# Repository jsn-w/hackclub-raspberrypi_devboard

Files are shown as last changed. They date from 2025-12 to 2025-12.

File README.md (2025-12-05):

# hackclub-raspberrypi_devboard
The hackclub-raspberrypi_devboard is a custom development board designed to be simple and easy to use, similar to an Arduino, but build with a RaspberryPi microcontroller.
There are many features, such as compatibility with USB-C, supports breadboard pitch, and works with different software (Arduino, CircuitPython, etc).

# Features, materials
- 29 GPIO pins (4 of them are also ADC)
- Voltage Regulator
- 12 MHz crystal oscillator
- External flash chip

# Schematic!


# PCB
The PCB was made within KiCad and has two layers, where the top and bottom layer both connect to GND. It would be beneficial to have a four layer PCB instead of two since the routings would be done easier by setting adding another power plane for 3.3V or VCC.


<p>There are currently errors for the flash chip since it was imported. The pads are too close to each other but I couldn't find a way to edit them.</p>


# Materials Used
- 1x USB_C_Receptacle_USB2.0_14P
- 1x MCP1700x-330xxTT
- 1x W25Q16JVUXIQ_TR
- 1x Crystal_SMD_3225
- 2x 01x20 pin connector
- 1x 01x03 pin connector
Capacitors
- 11x 100nF
- 2x  1uF
- 2x  10uF
- 2x  33pF
Resistors
- 4x 1.5k
- 1x 1k
- 2x 27

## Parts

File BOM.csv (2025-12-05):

Quantity | Cost | Part | Description | Link
1 | 0.29 | USB_C_Receptacle_USB2.0_14P | USB C Port | https://www.snapeda.com/parts/USB4105GFA/Global%20Connector%20Technology/view-part/
1 | 0.54 | MCP1700x-330xxTT | Low Dropout Regulator (LDO) | https://www.digikey.com/en/products/detail/microchip-technology/MCP1700T-3502E-TT/9643116?gclsrc=aw.ds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
1 | 0.67 | W25Q16JVUXIQ_TR | 16Mbit SPI Flash Memory | https://www.digikey.com/en/products/detail/winbond-electronics/W25Q16JVUXIQ-TR/15182017
1 | 0.38 | Crystal_SMD_3225 | SMD Crystal Oscillator (3225) | https://www.digikey.com/en/products/detail/abracon-llc/ABM8-12.000MHZ-12-B1U-T/9998039?gclsrc=aw.ds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

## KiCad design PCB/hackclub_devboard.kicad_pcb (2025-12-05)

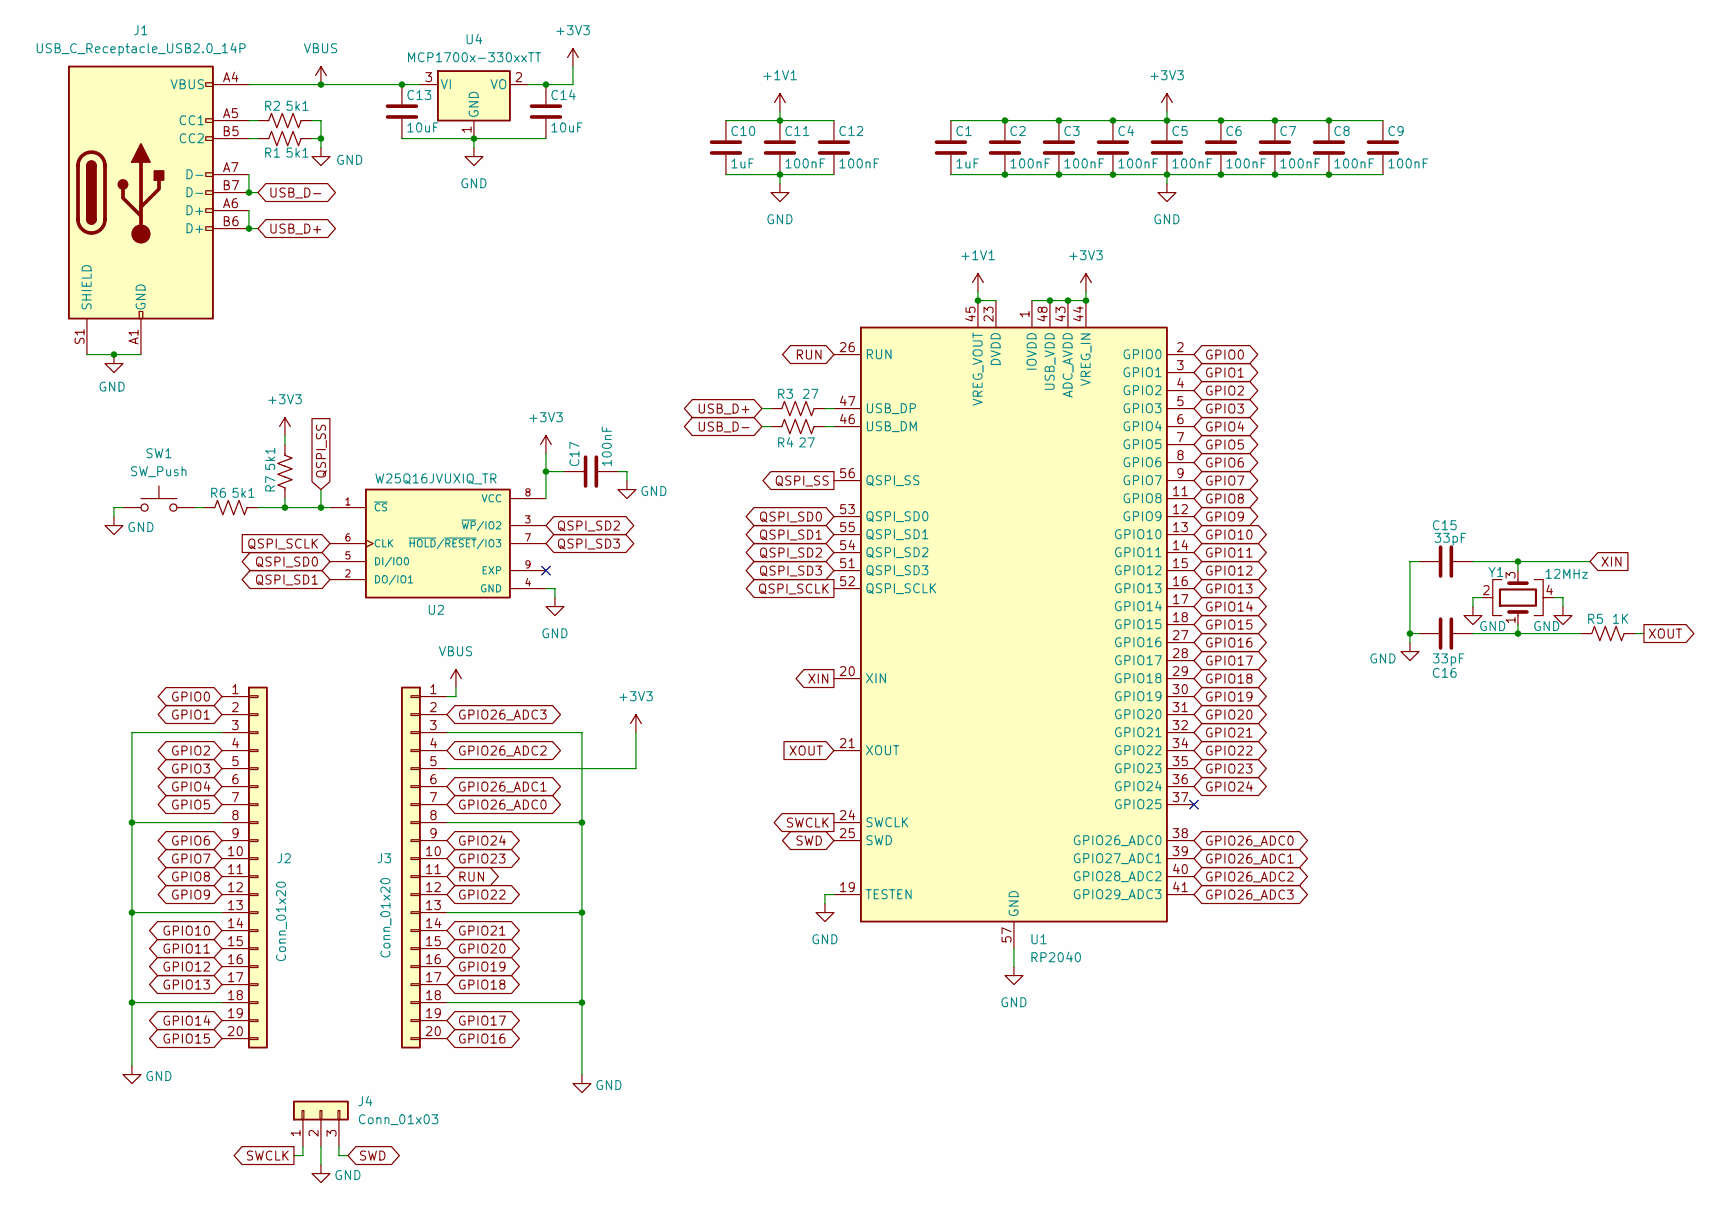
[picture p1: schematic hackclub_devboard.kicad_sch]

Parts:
C1, C10: 1uF; C_0402_1005Metric
C2, C3, C4, C5, C6, C7, C8, C9, C11, C12, C17: 100nF; C_0402_1005Metric
C13, C14: 10uF; C_0603_1608Metric
C15, C16: 33pF; C_0402_1005Metric
J1: USB_C_Receptacle_USB2.0_14P; USB_C_Receptacle_HRO_TYPE-C-31-M-12
J2, J3: Conn_01x20; PinHeader_1x20_P2.54mm_Vertical
J4: Conn_01x03; PinHeader_1x03_P2.54mm_Vertical
R1, R2, R6, R7: 5k1; R_0402_1005Metric
R3, R4: 27; R_0402_1005Metric
R5: 1K; R_0402_1005Metric
SW1: SW_Push; Crystal_SMD_3225-4Pin_3.2x2.5mm
U1: RP2040; QFN-56-1EP_7x7mm_P0.4mm_EP3.2x3.2mm
U2: W25Q16JVUXIQ_TR; IC_W25Q16JVUXIQ_TR; PARTREV H
U4: MCP1700x-330xxTT; SOT-23
Y1: 12MHz; Crystal_SMD_3225-4Pin_3.2x2.5mm

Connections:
+1V1: C10.1, C11.1, C12.1, U1.23 (DVDD), U1.45 (VREG_VOUT), U1.50 (DVDD)
+3V3: C1.1, C2.1, C3.1, C4.1, C5.1, C6.1, C7.1, C8.1, C9.1, C14.1, C17.1, J3.5, R7.2, U1.1 (IOVDD), U1.10 (IOVDD), U1.22 (IOVDD), U1.33 (IOVDD), U1.42 (IOVDD), U1.43 (ADC_AVDD), U1.44 (VREG_IN), U1.48 (USB_VDD), U1.49 (IOVDD), U2.8 (VCC), U4.2 (VO)
GND: C1.2, C2.2, C3.2, C4.2, C5.2, C6.2, C7.2, C8.2, C9.2, C10.2, C11.2, C12.2, C13.2, C14.2, C15.1, C16.1, C17.2, J1.A1 (GND), J1.A12 (GND), J1.B1 (GND), J1.B12 (GND), J1.S1 (SHIELD), J2.3, J2.8, J2.13, J2.18, J3.3, J3.8, J3.13, J3.18, J4.2, R1.2, R2.2, SW1.1, U1.19 (TESTEN), U1.57 (GND), U2.4 (GND), U4.1 (GND), Y1.2, Y1.4
GPIO0: J2.1, U1.2 (GPIO0)
GPIO1: J2.2, U1.3 (GPIO1)
GPIO2: J2.4, U1.4 (GPIO2)
GPIO3: J2.5, U1.5 (GPIO3)
GPIO4: J2.6, U1.6 (GPIO4)
GPIO5: J2.7, U1.7 (GPIO5)
GPIO6: J2.9, U1.8 (GPIO6)
GPIO7: J2.10, U1.9 (GPIO7)
GPIO8: J2.11, U1.11 (GPIO8)
GPIO9: J2.12, U1.12 (GPIO9)
GPIO10: J2.14, U1.13 (GPIO10)
GPIO11: J2.15, U1.14 (GPIO11)
GPIO12: J2.16, U1.15 (GPIO12)
GPIO13: J2.17, U1.16 (GPIO13)
GPIO14: J2.19, U1.17 (GPIO14)
GPIO15: J2.20, U1.18 (GPIO15)
GPIO16: J3.20, U1.27 (GPIO16)
GPIO17: J3.19, U1.28 (GPIO17)
GPIO18: J3.17, U1.29 (GPIO18)
GPIO19: J3.16, U1.30 (GPIO19)
GPIO20: J3.15, U1.31 (GPIO20)
GPIO21: J3.14, U1.32 (GPIO21)
GPIO22: J3.12, U1.34 (GPIO22)
GPIO23: J3.10, U1.35 (GPIO23)
GPIO24: J3.9, U1.36 (GPIO24)
GPIO26_ADC0: J3.7, U1.38 (GPIO26_ADC0)
GPIO26_ADC1: J3.6, U1.39 (GPIO27_ADC1)
GPIO26_ADC2: J3.4, U1.40 (GPIO28_ADC2)
GPIO26_ADC3: J3.2, U1.41 (GPIO29_ADC3)
unnamed: C16.2, R5.1, Y1.1
unnamed: J1.A5 (CC1), R2.1
unnamed: J1.B5 (CC2), R1.1
unnamed: R6.1, SW1.2
unnamed: R4.1, U1.46 (USB_DM)
unnamed: R3.2, U1.47 (USB_DP)
QSPI_SCLK: U1.52 (QSPI_SCLK), U2.6 (CLK)
QSPI_SD0: U1.53 (QSPI_SD0), U2.5 (DI/IO0)
QSPI_SD1: U1.55 (QSPI_SD1), U2.2 (DO/IO1)
QSPI_SD2: U1.54 (QSPI_SD2), U2.3 (~WP/IO2)
QSPI_SD3: U1.51 (QSPI_SD3), U2.7 (~HOLD/~RESET/IO3)
QSPI_SS: R6.2, R7.1, U1.56 (QSPI_SS), U2.1 (~CS)
RUN: J3.11, U1.26 (RUN)
SWCLK: J4.1, U1.24 (SWCLK)
SWD: J4.3, U1.25 (SWD)
USB_D+: J1.A6 (D+), J1.B6 (D+), R3.1
USB_D-: J1.A7 (D-), J1.B7 (D-), R4.2
VBUS: C13.1, J1.A4 (VBUS), J1.A9 (VBUS), J1.B4 (VBUS), J1.B9 (VBUS), J3.1, U4.3 (VI)
XIN: C15.2, U1.20 (XIN), Y1.3
XOUT: R5.2, U1.21 (XOUT)

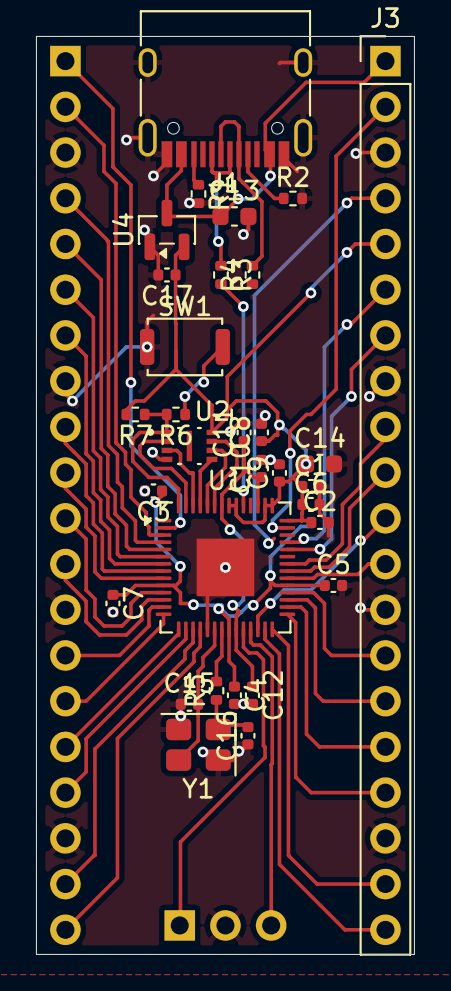
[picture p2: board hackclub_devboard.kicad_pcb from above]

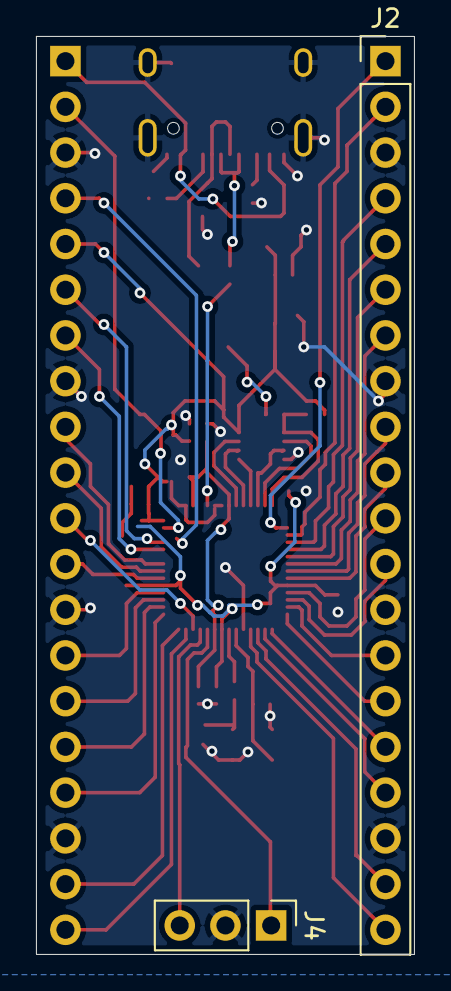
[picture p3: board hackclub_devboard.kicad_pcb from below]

Board: 2 copper layers, 21.0 x 51.0 mm, 33 parts (2 on the bottom side), 52 nets.

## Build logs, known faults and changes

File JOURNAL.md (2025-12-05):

# journal
Estimated time: 10 hours

## Firmware!
<p>This process took 2.5 hours (and counting) and was done on 12/2 but I didn't get the chance to actually journal this on time on the site.</p>
<p>This microcontroller could be used for anything, but I wanted to make a game similar to pacman, or pong. I have an Arduino UNO R4 Minima where I started prototyping the game. It includes having a joystick to control the position of the cursor. Once the devboard is assembled, I will transfer the Arduino program over.</p>


## Wiring the schematic
<p>I wired all the schematic on 12/3-12/4, and this process took approximately 2.5 hours</p>
<p>I routed the PCB, getting help from the <a href="https://pip-assets.raspberrypi.com/categories/814-rp2040/documents/RP-008371-DS-1-rp2040-datasheet.pdf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" target="_blank">RP2040 Datasheet</a>, page 11.</p>



<p>This helped me figure out what and where to connect the pins. I also found placing global labels to be really nice. Here is an image of me actually wiring things on a STM32 board:</p>

<p>Net labels makes it a lot cleaner since there aren't routings going everywhere.</p>
<p>Something really annoying about this portion is finding the right schematic and footprint for a part that you want to use, oftentimes there aren't any CAD files for the footprints.</p>

## Tracing PCB
<p>Tracing the pcb took approximately 5 hours and was completed on 12/4-12/5. It still needs some improvements on wiring so that it is more organized.</p>
<p>First, I placed everything in their relative spots based on the diagram below.</p>

<p>Then, I made sure that some modules were really close to the microcontroller (decoupling capacitors, crystal oscillators)</p>
<p>I realized that on a small board, the decoupling capacitors wouldn't be able to be that close to the microcontroller since there's a lot of wiring going on around those pins.</p>

<p>For a lot of the routing, I had to move a lot of wires down for optimal spacing so I can actually fit some of the capacitors and other components in.</p>
<p>In this portion, I had to rewire the entire section multiple times to allow space for components to be placed above it.</p>


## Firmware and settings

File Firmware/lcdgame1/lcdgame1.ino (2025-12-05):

#include <Wire.h>
#include <LiquidCrystal_I2C.h>

// Initialize the library with the I2C address found for your display
LiquidCrystal_I2C lcd(0x27, 16, 4);

byte customChar[] = {
    B00000,
    B00000,
    B00000,
    B11000,
    B11000,
    B00000,
    B00000,
    B00000
};

int xVal = 0;
int yVal = 0;
String displayArray[] = {
    "10000000000000000000",
    "00000000000000000000",
    "00000000000000000000",
    "00000000000000000000"
};


void setup() {
    Serial.begin(9600);

    lcd.init();
    lcd.backlight();

    pinMode(7, INPUT_PULLUP);

    // Print a message to the LCD
    lcd.setCursor(0, 0); // Set the cursor to column 0, row 0
    lcd.print("Hello, World!");
    lcd.setCursor(0, 1); // Move to the second row
    lcd.print("LCD 16x4 I2C");

    lcd.createChar(1, customChar);
    lcd.setCursor(0, 2);
    lcd.write(1);
    printArray();

}

void loop() {
    // Main loop - nothing to do here
    int x = analogRead(A1);
    int y = analogRead(A0);
    // Serial.print(x);
    // Serial.print("\t");
    // Serial.println(y);
    if(x>900) {
        moveRight();
        printArray();
    }
    if (x<150) {
        moveLeft();
        printArray();

    }


}

void moveRight() {
    displayArray[xVal][yVal] = '0';
    if(yVal<19) {
        yVal++;
    }
    displayArray[xVal][yVal] = '1';
}

void moveLeft() {
    displayArray[xVal][yVal] = '0';
    if(yVal>0) {
        yVal--;
    }
    displayArray[xVal][yVal] = '1';
}

void printArray() {
    for(int r=0; r<4; r++) {
        for(int c=0; c<20; c++) {
            lcd.setCursor(c, r);
            if (displayArray[r][c]=='1') {
                lcd.write(1);
            } else {
                lcd.print(" ");
            }
        }
    }
}

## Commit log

2025-12-05 Enhance README with project details and materials
    Added detailed description, features, and materials for the hackclub-raspberrypi_devboard.
2025-12-05 Add journal entry for PCB wiring and tracing
    Documented the process of wiring the schematic and tracing the PCB, including images and insights on component placement and routing challenges.
2025-12-05 Enhance JOURNAL.md with formatting and details
    Updated the journal with improved formatting and additional explanations about wiring and PCB design.
2025-12-05 Document firmware and PCB development progress
    Added journal entries detailing firmware development, schematic wiring, and PCB tracing processes.
2025-12-05 Update PCB section with new images and formatting
    Updated PCB images and fixed formatting issues in the README.
2025-12-05 Enhance README with PCB design information
    Added details about the PCB design and its limitations.
2025-12-05 Revise PCB section in README with images and notes
    Updated PCB section with additional images and notes on design limitations.
